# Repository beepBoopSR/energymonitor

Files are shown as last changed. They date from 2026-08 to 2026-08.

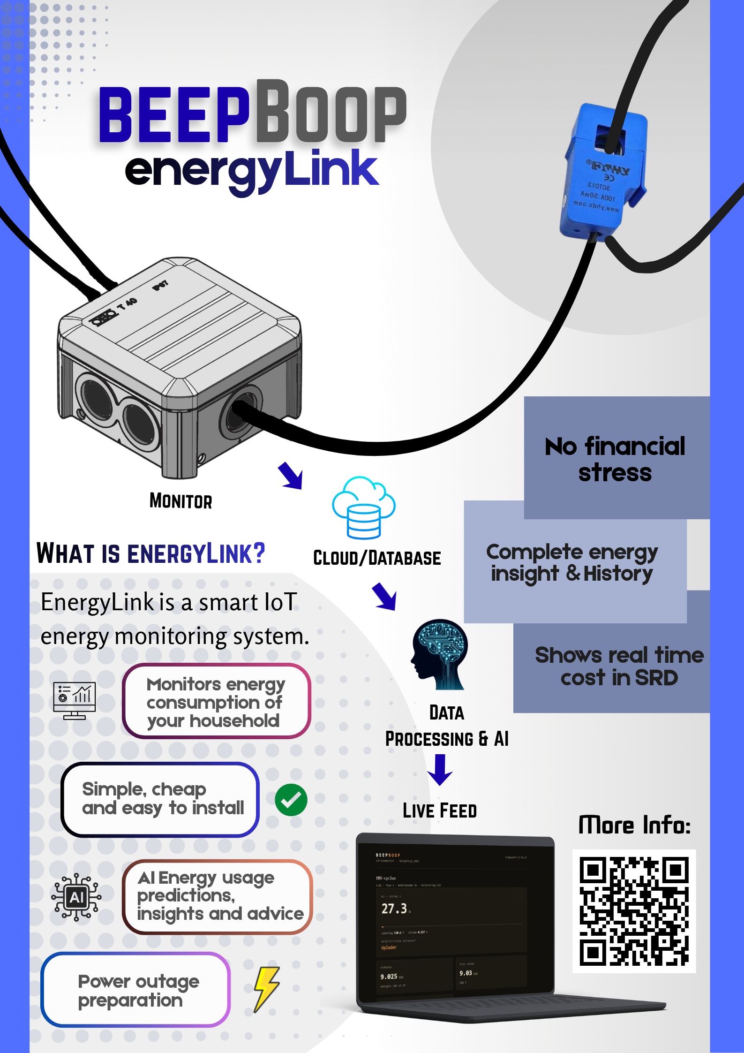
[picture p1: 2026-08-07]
Extras/beepBoop energylink poster.png

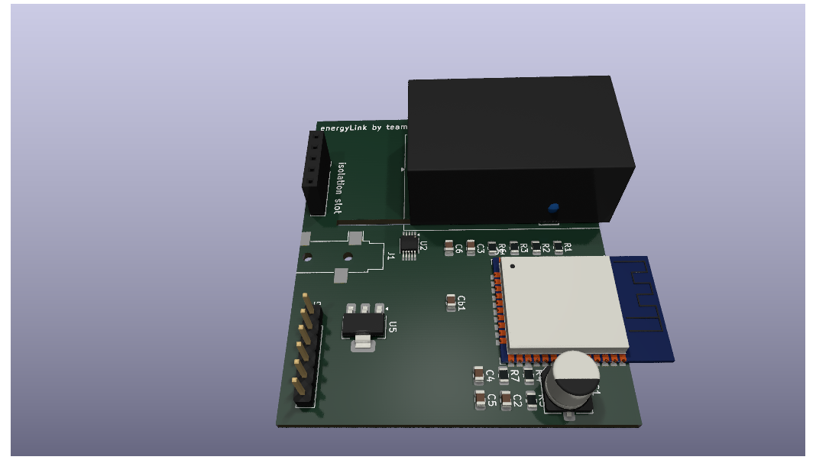
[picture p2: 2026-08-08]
energyLink PCB/Pictures 3D PCB/energyLink2.png

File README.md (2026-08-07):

# energyLink

**An AI home-energy monitor built for Surinamese households.**
team **beepBoop** · Hackomation 2026

energyLink clamps onto a home's main power line and continuously measures
consumption. For the first time, a household can watch its electricity bill build
in real time — in SRD, against the *actual* tiered EBS tariff — and get grounded,
practical advice in **Dutch and Sranan Tongo**, before the bill ever arrives.

---

## The problem it solves

- **The EBS household tariff is tiered.** The more you use, the more each next kWh
  costs — and the bill only arrives at the end of the cycle, as a surprise.
- **The grid is unstable.** Outages and brownouts are a daily reality.
- **Existing energy monitors don't fit Suriname.** They assume a stable grid, a flat
  tariff, and an English-speaking user, and none of them can tell you your EBS bill.

energyLink makes consumption, cost, and grid quality visible and predictable, in the
user's own language.

---

## What it does

- **Live power & live cost** — watts, volts, amps, and the cost *per hour* at the
  current draw, in SRD, updating in real time.
- **Accurate EBS billing** — tiered energy charge, per-phase basis fee, subsidy bands,
  and a bill prediction — all aligned to the household's EBS billing cycle, not the
  calendar month.
- **Tariff-band awareness** — shows where you sit across the tiers and how far to the
  next (more expensive) band.
- **Grid monitoring** — detects and logs outages and brownouts, with buffering so no
  data is lost when the power flickers.
- **AI advisory** — grounded, bilingual (Dutch + Sranan Tongo) advice based on the
  household's real measured data.
- **Appliance recognition** — a trained classifier identifies the *type* of the
  dominant load (resistive heater / motor / switching charger) from its current
  signature.
- **Per-circuit clamps** — support for naming and monitoring individual circuits.

---

## Architecture

```
  ESP32 + sensors            Node.js backend             Next.js frontend
  ───────────────            ───────────────             ────────────────
  ADS1115 (I²C)              POST /api/readings          polls /api/dashboard
  SCT-013 current   ──WiFi──▶  reconstruct time   ◀──HTTP──  every 5s, renders
  ZMPT101B voltage             store + analyse             live dashboard
                               SQL billing model
                                    │
                                    ▼
                               Supabase (Postgres)
```

- **Device → backend:** the ESP32 measures and POSTs readings; the backend
  reconstructs timestamps (handling offline buffering), stores them, and runs grid /
  anomaly / appliance checks on each reading.
- **Backend → frontend:** the frontend never talks to the device or database directly —
  it polls the backend's HTTP endpoints, which run the SQL billing model and return a
  single JSON payload.
- **Billing lives in the database** as data-driven SQL functions, so a tariff change is
  a data update, not a code change — and the same model serves the dashboard, the
  prediction, and the AI from one source of truth.

---

## Repository structure

```
energymonitor/
├── 3D-models hardware case/     3D model of an enclosure (designed but not used —
│                                 we bought an off-the-shelf case; kept for reference)
├── Back-end/                    Node.js + Express backend
│   ├── beepBoop-Back-End/       the runnable backend project (see below)
│   └── AI_training_appliance_models/   appliance-classifier training pipeline (see below)
├── C++ esp32 Firmwares/         ESP32 firmware — the full monitoring firmware, plus a
│                                 separate firmware used to capture waveforms for
│                                 appliance-fingerprint training
├── Extras/                      Business Model Canvas, poster, circuit diagram
├── SQL queries and functions/   Supabase schema, billing functions, seed data
├── api/                         API-related files
├── app/                         Next.js frontend (see below)
├── landingPage/                 Standalone marketing landing page
├── site/                        site assets
├── CLAUDE.md                    project notes
├── LICENSE
├── README.md                    this file
└── package.json
```

> The trees below list the **key files and their roles** — the important application
> code — rather than every file in the project. Config, generated, and dependency
> files are omitted for readability.

### Backend — `Back-end/beepBoop-Back-End/`

```
├── index.js                    Express app entry; registers routes, enables CORS
├── config/
│   └── supabase.js             configured Supabase client
├── routes/
│   ├── readings.js             POST /api/readings  ·  GET /api/dashboard
│   ├── tips.js                 GET /api/latest-tip  ·  POST /api/generate-tip
│   ├── settings.js             GET/POST /api/settings (phase, cycle, budget)
│   └── clamps.js               GET /api/clamps  ·  POST /api/clamps/rename
├── services/
│   ├── readings.js             reading ingestion + summary assembly
│   ├── reconstruction.js       timestamp reconstruction (offline buffering)
│   ├── gridMonitor.js          outage / brownout detection (with hysteresis)
│   ├── anomalyMonitor.js       power-spike + overuse detection
│   ├── applianceMonitor.js     appliance classifier — live inference
│   ├── energyContext.js        gathers the real context for the AI
│   ├── prompt.js               builds the grounded, bilingual AI prompt
│   ├── tips.js                 AI tip generation + retrieval
│   └── billPrediction.js       statistical bill projection (single source)
└── .env                        Supabase + Gemini keys (NOT committed)
```

### Appliance-classifier training — `Back-end/AI_training_appliance_models/`

```
├── 1_extract_features.py       waveform captures -> electrical features (CSV)
├── 2_train_model.py            train + cross-validate decision tree -> JSON
├── 3_inference_reference.js    reference of the JS inference (live in services/)
├── appliance_tree.json         the exported trained model
├── captures/                   example current-waveform captures
├── README.md                   pipeline documentation
└── NILM_future_work.md         why multi-appliance disaggregation was shelved
```

### Frontend — `app/app/`

```
├── app/
│   ├── page.tsx                redirects to /dashboard
│   ├── layout.tsx              sidebar shell (SidebarProvider)
│   ├── globals.css             energyLink light theme
│   ├── dashboard/page.tsx      main dashboard (live power, cost, tiers, AI, graphs)
│   ├── clamp/[id]/page.tsx     per-clamp detail (mini-dashboard + rename)
│   ├── uitval/page.tsx         outages (history)
│   ├── instellingen/page.tsx   settings (phase, EBS cycle, budget)
│   └── over/page.tsx           about / project story
├── components/
│   ├── app-sidebar.tsx         collapsible energyLink sidebar
│   ├── nav-main.tsx            nav items + active highlight
│   ├── nav-user.tsx            device identity footer
│   ├── clamps-section.tsx      dashboard Circuits section
│   └── ui/                     shadcn/ui components
├── lib/
│   └── api.ts                  API client, typed responses, mock data, USE_MOCK flag
├── next.config.ts
├── package.json
└── tsconfig.json
```

---

## Running it

Both the backend and the frontend must be running. The device (or synthetic data)
feeds the backend; the frontend polls the backend.

### Backend (port 3000)

```bash
cd Back-end
cd beepBoop-Back-End
node index.js
```

The backend serves on **port 3000** and exposes the API the frontend reads.

### Frontend (port 3001)

```bash
cd app
cd app
npm install          # first time only
npm run dev -- -p 3001
```

The frontend runs on **port 3001** (kept separate from the backend's 3000) and is
available at `http://localhost:3001`. Opening it redirects to the dashboard.

> The frontend fetches from the backend at `http://localhost:3000`. CORS is enabled on
> the backend so the cross-port requests are allowed. If the dashboard shows
> "kan geen verbinding maken," the backend isn't running or isn't reachable.

---

## Configuration

- **Backend:** environment variables for the Supabase connection and the AI (Gemini)
  API key live in the backend's environment (see the backend's own config). **Do not
  commit real keys.**
- **Frontend:** the API base URL and device id are set in the frontend's `lib/api.ts`.
  A `USE_MOCK` flag there switches between mock data and the live backend.
- **Database:** the SQL to create the schema, functions, and seed data is in
  `SQL queries and functions/` — run the table definitions first, then the functions,
  then the seed data.

---

## Firmware

The `C++ esp32 Firmwares/` folder contains two firmwares:

1. **Monitoring firmware** — the production firmware: samples voltage and current via
   the ADS1115, computes RMS/power/energy and waveform features, and POSTs readings to
   the backend over WiFi, with offline buffering and timestamp reconstruction.
2. **Fingerprint-capture firmware** — a separate build used during development to
   capture raw current waveforms of known appliances, for training the appliance
   classifier.

---

## Hardware

A sensing front-end around an ESP32:

- **ESP32 DevKit** — microcontroller with WiFi
- **ADS1115** — 16-bit I²C ADC (address 0x48; SDA→D21, SCL→D22)
- **SCT-013-000** — non-invasive current clamp, on the ADS1115 *differential* input
  A0–A1 with a 220 Ω burden resistor
- **ZMPT101B** — isolated AC voltage sensor, single-ended on A2

The circuit diagram is in `Extras/`. An enclosure 3D model is in
`3D-models hardware case/` (we used an off-the-shelf case in the end, but kept the
model).

---

## The AI, honestly scoped

energyLink uses AI in three distinct ways, and is deliberately precise about which is
which:

1. **Appliance recognition — trained machine learning.** A decision-tree classifier,
   trained on captured current waveforms, identifies the *type* of load from its
   electrical signature. (Training pipeline documented separately.)
2. **Advisory — a language model, grounded.** An LLM interprets the household's real
   computed data into personalized, bilingual advice, constrained so it never invents
   appliances or amounts.
3. **Anomaly detection — algorithmic.** Threshold-based spike and unusual-usage
   detection (not a trained model, and not described as one).

The **bill prediction is a transparent statistical projection, not AI** — we don't
dress it up as one. Multi-appliance disaggregation (NILM) was prototyped and shelved
for hardware reasons, documented as future work.

---

## Team

Built by team **beepBoop**, students at the Anton de Kom University of Suriname (ADeKUS),
for **Hackomation 2026**.

---

## License

See `LICENSE`.

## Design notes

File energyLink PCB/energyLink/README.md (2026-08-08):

# energyLink — KiCad project (team beepBoop)

Home energy monitor for Suriname's grid (120–127 V, 60 Hz). Clamps the main
live conductor, measures consumption, buffers to ESP32 flash when WiFi is down,
and infers mains outages from its own power-loss timestamps.

## Files
| File | What it is |
|---|---|
| `energyLink.kicad_sch` | Schematic — all components with net-label connectivity |
| `energyLink.kicad_pcb` | PCB — 55×40 mm outline, isolation slot, zoned placement |
| `energyLink.net` | Netlist — importable into Pcbnew if needed |
| `energyLink.kicad_pro` | Project file — open this in KiCad first |

Open `energyLink.kicad_pro` in KiCad 7 or 8.

## Please read — these files were generated programmatically
They are structurally valid and parse cleanly, but they were built without the
KiCad GUI, so treat them as a strong starting point, not a finished board:

1. Symbols are simple labelled rectangles with correct pins and nets. On first
   open, run **Inspect → Electrical Rules Check (ERC)**. Connectivity is carried
   by net labels on each pin, which is valid but will raise a few "no power flag"
   ERC notes — add PWR_FLAG on +3V3 / +5V / GND to clear them.
2. Footprints are named to standard KiCad libraries (`Converter_ACDC`,
   `RF_Module`, etc.). If a name doesn't resolve on your install, reassign via
   **Tools → Footprint Assignment**. The `.kicad_pcb` uses simplified 2-pad
   placeholders so you can see the zoned layout; swap in the real footprints
   before routing.
3. The PCB shows **placement and the isolation strategy**, not routed copper.
   Route it in Pcbnew — keep every mains trace inside the left zone.

## Design summary
- **Isolated SELV logic.** The only mains-referenced parts are J3, F1, RV1, the
  HLK-PM01 primary, and the ZMPT101B primary. CT, ZMPT, and HLK all isolate, so
  the ESP32/ADS1115 ground never touches mains — which is what makes the
  external 3.5 mm CT jack safe to handle.
- **Current:** SCT-013-000 → 3.5 mm jack → 22 Ω burden across ADS1115 A0–A1,
  biased to ~1.65 V via the VMID divider (R2/R3/Cb).
- **Voltage:** ZMPT101B isolated output → ADS1115 A2 (VSENSE).
- **Power:** HLK-PM01 (mains→5 V) → AMS1117-3.3 → 3V3. C1 470 µF bulk at the
  ESP32 prevents WiFi brownout resets.
- **Safety:** fuse + MOV on the line input; ≥6–8 mm creepage and a milled slot
  between mains and SELV zones (CAT III near a panel). A real product needs
  proper safety testing/certification and, in most places, electrician install.

## Productization notes (not in these files)
- Consider replacing the ADS1115 with an **ADE7953** metering IC for true active
  power / power factor (the ADS1115 multiplexes, so V and I aren't sampled
  simultaneously). Keep it inside the isolated domain, fed from the ZMPT output.
- **ESP32-C3-MINI-1** is smaller/cheaper and plenty for this workload.

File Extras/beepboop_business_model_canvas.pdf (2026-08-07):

# beepBoop — Business Model Canvas

AI-powered home energy monitor for Suriname · Team beepBoop, Anthon de Kom Universiteit van Suriname · Hackomation 2026

Draft v1 — July 2026

KEY PARTNERS

- EBS (Energiebedrijven Suriname) — tariff data, potential rollout partner
- Licensed electricians — panel installation network
- Local hardware importers (ESP32, sensors, clamps)
- Telesur / Digicel — connectivity for IoT data
- ADeKUS — engineering talent, credibility, pilot households
- Google (Gemini API) — AI advisory layer, model-agnostic by design

KEY ACTIVITIES

- Hardware assembly & per-unit calibration
- Firmware & platform development (offline-first)
- AI advisory: tips in Dutch & Sranan Tongo
- Tiered EBS billing engine & bill prediction
- Installation coordination with electricians

KEY RESOURCES

- Proprietary firmware: outage-resilient logging, timestamp reconstruction
- Tariff-aware billing engine (EBS block pricing)
- Sensor pipeline: current clamps + voltage sensing
- Growing dataset of Surinamese household usage
- Bilingual AI prompt & advisory system

VALUE PROPOSITIONS

- See your electricity bill BEFORE it arrives — tier-aware prediction
- Advice in your own language: Dutch & Sranan Tongo
- Built for Suriname's unstable grid: outage & brownout logging, offline-first
- Know which tariff tier you are in and how to stay under the next one
- Budget mode: set a monthly limit, get warned before you exceed it
- Evidence of grid quality (outage history) households can act on
- No smart meter required — clips onto existing breaker panel
- Future: per-appliance insight via AI fingerprinting

CUSTOMER RELATIONSHIPS

- Self-service dashboard (web app)
- AI advisor as ongoing personal touchpoint
- Installation moment = trust-building visit
- Community word-of-mouth (bill savings are visible)

CHANNELS

- Direct sales via landing page & social media
- Electrician referral network
- Hardware shops as resellers
- Future: EBS partnership channel

CUSTOMER SEGMENTS

- PRIMARY: Surinamese households on EBS household tariff, bill-sensitive, hit by tier jumps
- Households with frequent outages wanting grid evidence
- Budget-conscious families (subsidy-band households)
- SECONDARY: small businesses (niet-huishoudelijk flat 4.820/kWh — simpler billing, price-sensitive)
- FUTURE: groot verbruikers — time-of-use, kVA demand & power-factor optimisation (measurable ROI, no consumption cut needed)

COST STRUCTURE

- Per-unit hardware BOM: ESP32, ADS1115, SCT-013 clamp(s), ZMPT101B, PSU, enclosure
- Installation labour (electrician fee per unit) · Cloud & database hosting (Supabase)
- AI API usage (batched, ~fractions of a cent per advisory) · Support & calibration

REVENUE STREAMS

- Device sale (one-time, hardware + installation)
- Monthly subscription: AI advisory, bill prediction, outage history
- FUTURE: commercial tier for businesses (demand & power-factor analytics, premium pricing)
- FUTURE: anonymised consumption insights for utility planning (with consent)

# Notes, Assumptions & Open Questions

## Why this problem, why here

- EBS household billing is tiered (1.971 / 2.850 / 3.330 / 4.680 SRD per kWh, Dec 2024 sheet). Crossing a block raises the marginal price of every further kWh by up to 45%. Households cannot see this coming; beepBoop makes the tier position visible and predicts the bill.
- Grid instability is normal life in Suriname: the prototype has already logged real brownouts (down to 103 V) and outages during bench testing. Outage history is evidence households currently have no way to capture.
- Advisory in Sranan Tongo is a differentiator no imported product (Sense, Emporia) offers.

## What is proven vs. assumed

- PROVEN in prototype: calibrated current & voltage sensing, tiered billing engine, offline-first logging with timestamp reconstruction, outage/brownout detection, bilingual AI advisory grounded in measured data.
- ASSUMED, to validate: willingness to pay (device price & subscription level unset), installation cost per unit, subsidy band mechanics (placeholder 100 SRD in current build), whether Dec 2024 tariffs still hold.

## Unit economics (to be filled with real quotes)

- BOM target: components are commodity parts; production would replace the ADS1115 with a metering IC (e.g. ATM90E32) for multi-circuit and power-factor accuracy. Pricing decision pending importer quotes.
- AI cost per user is negligible at batched-advisory volumes (fractions of SRD 0.01 per tip on free/flash-tier models); the system is model-agnostic (Gemini today, swappable).

## Scaling path

- Households first (this canvas). Small business second: flat 4.820/kWh makes billing simpler than households.
- Groot verbruikers third: time-of-use tariffs, kVA demand charges and cosphi penalties mean businesses can cut bills without cutting consumption — load shifting, peak flattening, power-factor correction. Requires simultaneous-sampling metering hardware; a deliberate v2.

beepBoop · Hackomation 2026 · Tariff figures from EBS sheet dated December 2024 — verification pending. Subsidy amount is a placeholder.

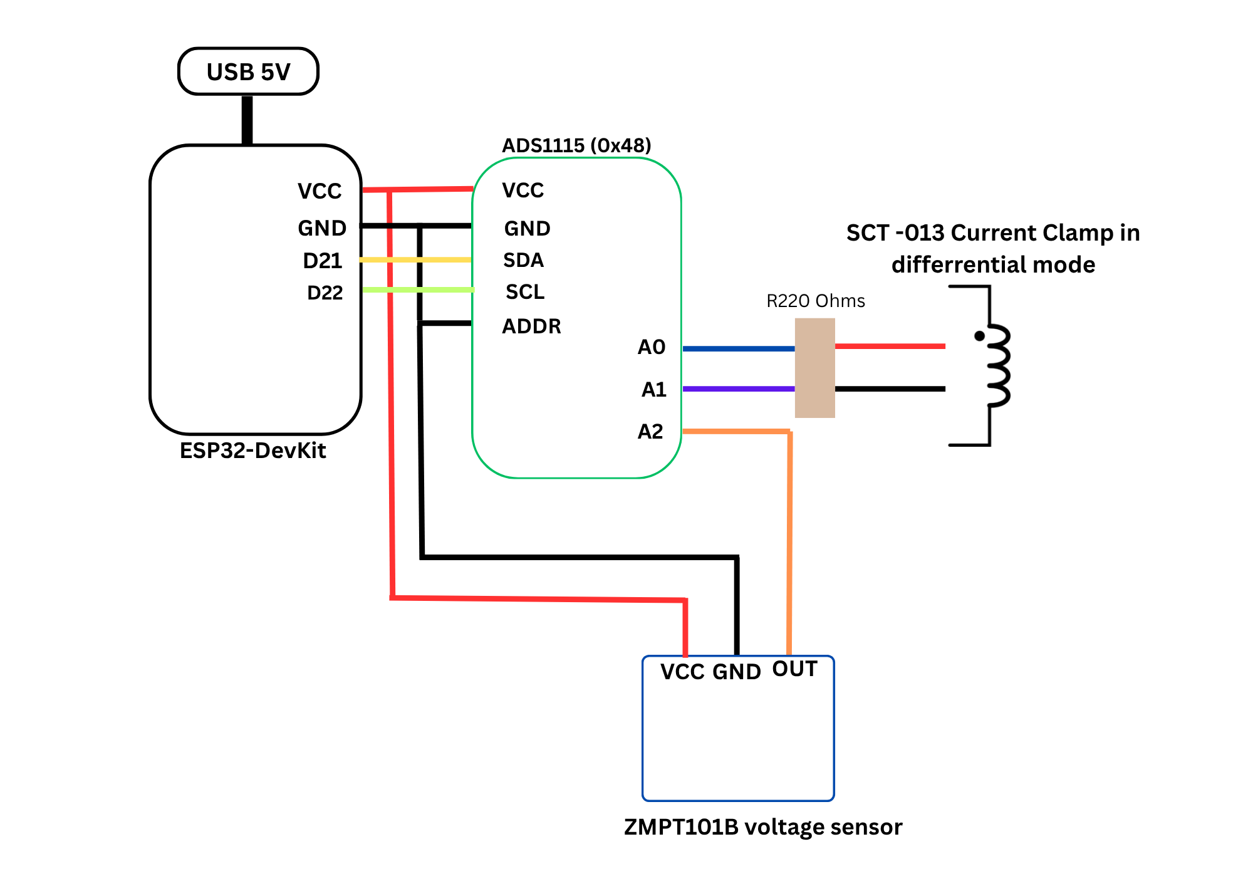
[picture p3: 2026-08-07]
Extras/hardwareCircuitDiaphgram.png

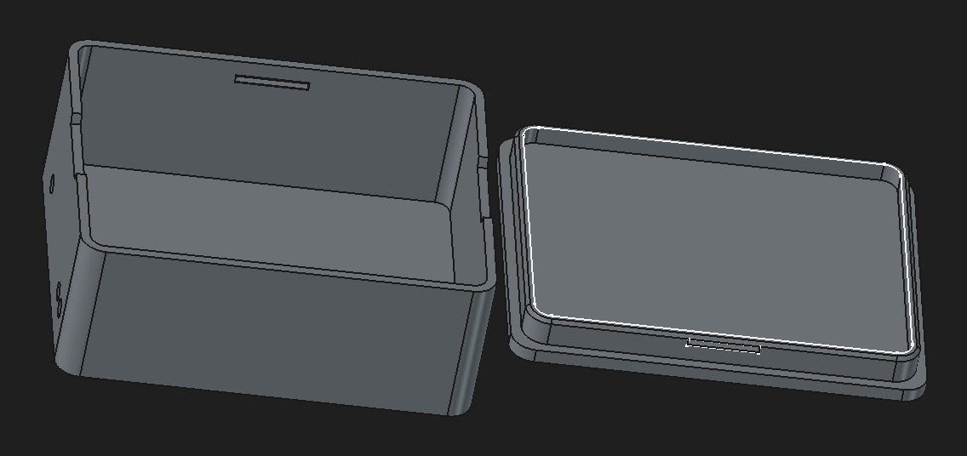
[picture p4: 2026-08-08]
3D-models hardware case/3d model picture.jpeg

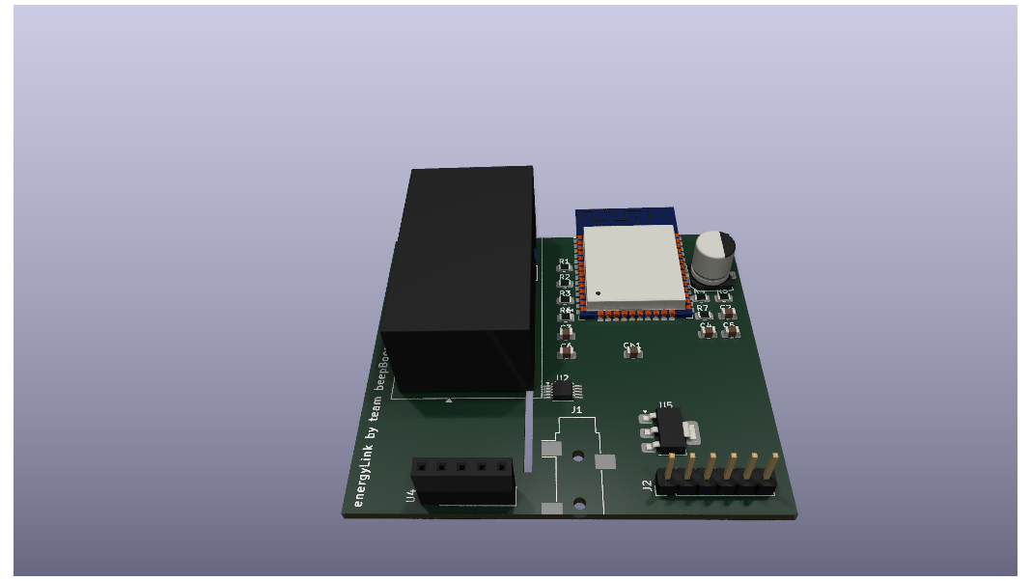
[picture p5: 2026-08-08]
energyLink PCB/Pictures 3D PCB/energyLink.png

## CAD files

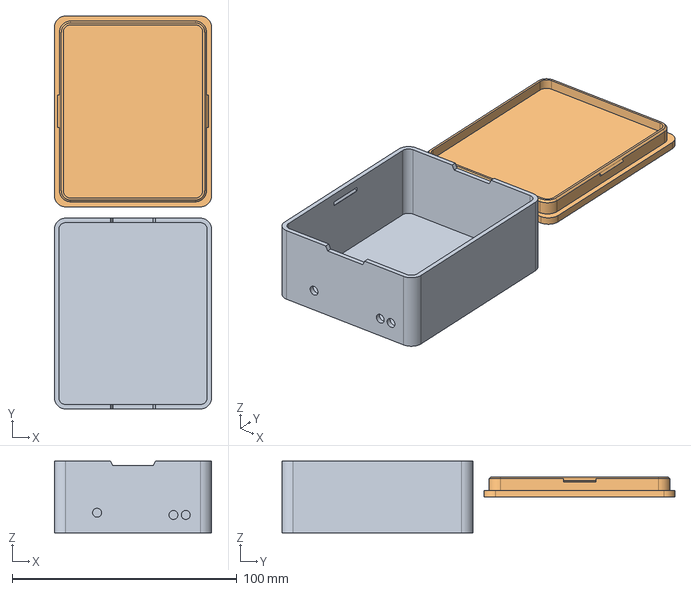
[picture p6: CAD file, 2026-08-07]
3D-models hardware case/energyLinkCase.FCStd
70.0 x 175.0 x 32.0 mm
lid

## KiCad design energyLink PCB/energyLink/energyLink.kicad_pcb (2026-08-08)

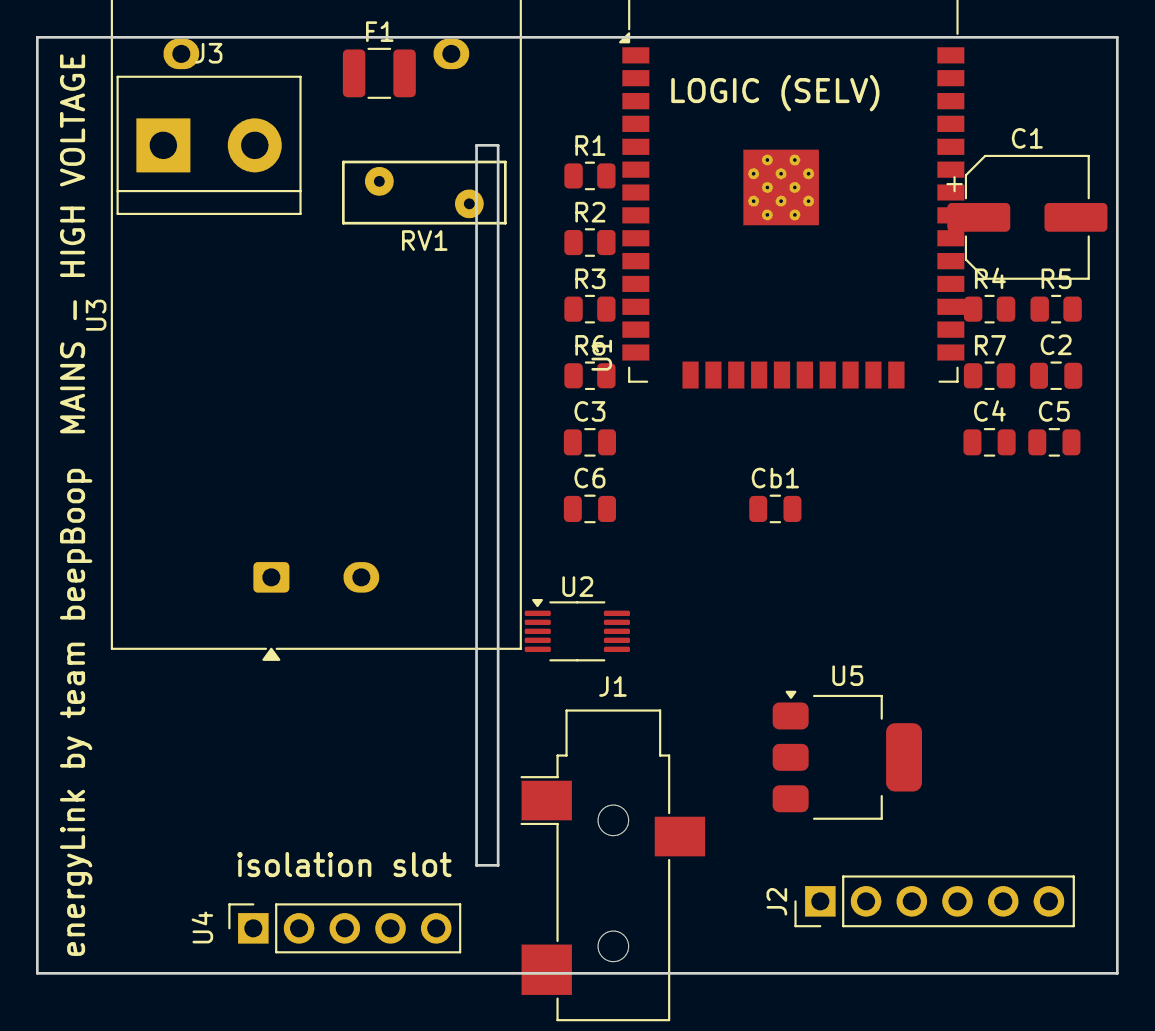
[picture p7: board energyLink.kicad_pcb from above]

Board: 2 copper layers, 60.0 x 52.0 mm, 24 parts (0 on the bottom side), 15 nets, no tracks yet.

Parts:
C1: 470uF_bulk; CP_Elec_6.3x7.7
C2, C3, C6: 100nF; C_0805_2012Metric
C4, C5: 10uF; C_0805_2012Metric
Cb1: 10uF_bias; C_0805_2012Metric
F1: Fuse_500mA_slow; Fuse_1210_3225Metric
J1: 3.5mm_CT_jack; Jack_3.5mm_CUI_SJ-3523-SMT_Horizontal
J2: Prog_1x6; PinHeader_1x06_P2.54mm_Vertical
J3: Mains_1x2; TerminalBlock_bornier-2_P5.08mm
R1: 22R_burden; R_0805_2012Metric
R2, R3: 100k; R_0805_2012Metric
R4: 4k7_SDA; R_0805_2012Metric
R5: 4k7_SCL; R_0805_2012Metric
R6: 10k_EN; R_0805_2012Metric
R7: 10k_IO0; R_0805_2012Metric
RV1: MOV_150VAC; RV_Disc_D9mm_W3.4mm_P5mm
U1: ESP32-WROOM-32
U2: ADS1115; VSSOP-10_3x3mm_P0.5mm
U3: HLK-PM01; Converter_ACDC_Hi-Link_HLK-PMxx
U4: ZMPT101B; PinSocket_1x05_P2.54mm_Vertical
U5: AMS1117-3.3; SOT-223-3_TabPin2

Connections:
/+3V3: C1.1, C2.1, C3.1, C5.1, J2.2 (3V3), R2.1, R4.2, R5.2, R6.2, R7.2, U1.1 (3V3), U2.1 (VDD), U4.3 (VCC), U5.3 (VOUT)
/+5V: C4.1, C6.1, U3.3 (+Vo), U5.1 (VIN)
/CT_A0: R1.1, U2.6 (A0)
/EN: J2.3 (EN), R6.1, U1.3 (EN)
/GND: C1.2, C2.2, C3.2, C4.2, C5.2, C6.2, Cb1.2, J2.1 (GND), R3.2, U1.2 (GND), U2.2 (GND), U2.5 (ADDR), U3.4 (-Vo), U4.5 (GND), U5.2 (GND)
/IO0: J2.4 (IO0), R7.1, U1.4 (IO0)
/L_FUSED: F1.2, RV1.1, U3.1 (L), U4.1
/L_IN: F1.1, J3.1 (L)
/N_MAINS: J3.2 (N), RV1.2, U3.2 (N), U4.2
/RX: J2.6 (RX), U1.8 (RXD0)
/SCL: R5.1, U1.6 (IO22_SCL), U2.3 (SCL)
/SDA: R4.1, U1.5 (IO21_SDA), U2.4 (SDA)
/TX: J2.5 (TX), U1.7 (TXD0)
/VMID: Cb1.1, R1.2, R2.2, R3.1, U2.7 (A1)
/VSENSE: U2.8 (A2), U4.4 (OUT)

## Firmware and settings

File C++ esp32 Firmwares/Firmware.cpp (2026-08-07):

#include <Wire.h>
#include <Adafruit_ADS1X15.h>
#include <WiFi.h>
#include <HTTPClient.h>
#include <time.h>
#include <LittleFS.h>

Adafruit_ADS1115 ads;

// WIFI + BACKEND
const char* WIFI_SSID     = "Ishaan's S23 FE";
const char* WIFI_PASSWORD = "ishaanoedit";
const char* SERVER_URL    = "http://10.182.168.64:3000/api/readings";
const char* DEVICE_ID     = "beepboop_001";

// SENSOR CALIBRATION
const float ADS_GAIN_VOLTS      = 0.0001875;
const float BURDEN_RESISTOR     = 22.0;
const int   CT_TURNS            = 2000;
const float CURRENT_FACTOR      = (float)CT_TURNS / BURDEN_RESISTOR;
const float CURRENT_CALIBRATION = 0.1255;   // 60W iron, verified with 30W
const float VOLTAGE_CALIBRATION = 1031.6;;     // multimeter @ 122.4V

// No tariff constant here — pricing is tiered and depends on the
// household's monthly cumulative total, which the device cannot know.
// The device reports energy; the database prices it.

// TIME (hardened)
const long  GMT_OFFSET_SEC      = -3 * 3600;
const int   DAYLIGHT_OFFSET_SEC = 0;
bool          timeIsSynced = false;
unsigned long lastSync     = 0;
const unsigned long SYNC_INTERVAL = 6UL * 3600UL * 1000UL;

// ADAPTIVE INTERVAL
const unsigned long INTERVAL_ONLINE    = 3000;
const unsigned long INTERVAL_OFFLINE_1 = 10000;
const unsigned long INTERVAL_OFFLINE_2 = 60000;
const unsigned long INTERVAL_OFFLINE_3 = 300000;
unsigned long offlineSince    = 0;
unsigned long lastSend        = 0;
unsigned long currentInterval = INTERVAL_ONLINE;

// STORAGE
const char*  BUFFER_FILE = "/buffer.txt";
const size_t MAX_BUFFER_BYTES = 1200000;

// STATE
long sequenceNumber = 0;

// SAMPLING
const unsigned long CURRENT_WINDOW_MS = 200;
const int CURRENT_AVG_WINDOWS = 5;
const int VOLTAGE_SAMPLES     = 256;

//For appliance fingerprinting
struct Features { float rms, peak, crest, form, shape; };

// Fast readings
struct Reading {
  float voltage, current, watts, kwh;
  float crest, form, shape, peak;
};

//For testing
unsigned long t;



void setup() {
  Serial.begin(115200);
  delay(1000);
  Serial.println("beepBoop — firmware v2 (energy reporting, tiered billing)");

  if (!LittleFS.begin(true)) { Serial.println("LittleFS failed."); while (1); }
  Wire.begin(21, 22);
  if (!ads.begin()) { Serial.println("ADS1115 not found."); while (1); }
  ads.setDataRate(RATE_ADS1115_860SPS);
  ads.setGain(GAIN_TWOTHIRDS);

  connectWiFi();
  Serial.print("Initial time sync");
  syncTime();
  Serial.println("Setup complete.\n");
}


// WIFI
void connectWiFi() {
  if (WiFi.status() == WL_CONNECTED) return;
  WiFi.begin(WIFI_SSID, WIFI_PASSWORD);
  int tries = 0;
  while (WiFi.status() != WL_CONNECTED && tries < 20) {
    delay(500); Serial.print("."); tries++;
  }
}


// HARDENED TIME
void syncTime() {
  configTime(GMT_OFFSET_SEC, DAYLIGHT_OFFSET_SEC,
             "pool.ntp.org", "time.google.com", "time.nist.gov");
  struct tm t; int tries = 0;
  while (!getLocalTime(&t) && tries < 10) { delay(500); Serial.print("."); tries++; }
  if (tries < 10) { timeIsSynced = true; lastSync = millis(); Serial.println(" synced"); }
  else Serial.println(" failed, will retry");
}

void maintainTime() {
  if (WiFi.status() == WL_CONNECTED &&
      (!timeIsSynced || millis() - lastSync > SYNC_INTERVAL)) syncTime();
}

String getTimestamp() {
  struct tm t;
  if (!timeIsSynced || !getLocalTime(&t)) return "UNSYNCED";
  char buf[25];
  sprintf(buf, "%04d-%02d-%02dT%02d:%02d:%02d",
          t.tm_year+1900, t.tm_mon+1, t.tm_mday, t.tm_hour, t.tm_min, t.tm_sec);
  return String(buf);
}


// ADAPTIVE INTERVAL 
unsigned long getInterval() {
  if (WiFi.status() == WL_CONNECTED) { offlineSince = 0; return INTERVAL_ONLINE; }
  if (offlineSince == 0) offlineSince = millis();
  unsigned long dur = millis() - offlineSince;
  if (dur < 10UL*60*1000)      return INTERVAL_OFFLINE_1;
  else if (dur < 60UL*60*1000) return INTERVAL_OFFLINE_2;
  else                         return INTERVAL_OFFLINE_3;
}

//VOLTAGE (A2 single-ended)

float readVoltage() {
  long sumRaw = 0; float sumSq = 0;
  for (int i = 0; i < VOLTAGE_SAMPLES; i++) sumRaw += ads.readADC_SingleEnded(2);
  float mid = (float)sumRaw / VOLTAGE_SAMPLES;
  for (int i = 0; i < VOLTAGE_SAMPLES; i++) {
    float s = ads.readADC_SingleEnded(2) - mid;
    float v = s * ADS_GAIN_VOLTS; sumSq += v*v;
  }
  float voltage = sqrt(sumSq / VOLTAGE_SAMPLES) * VOLTAGE_CALIBRATION;
  if (voltage < 20) voltage = 0.0;
  return voltage;
}

// UNIFIED READING — one current window feeds RMS + shape features

Reading takeReading(float elapsedSec) {
  const int N = 256;
  static int16_t buf[256];

  long sum = 0;
  for (int i = 0; i < N; i++) { buf[i] = ads.readADC_Differential_0_1(); sum += buf[i]; }
  float mid = (float)sum / N;

  float sumSq = 0, sumAbs = 0, peak = 0;
  for (int i = 0; i < N; i++) {
    float c = buf[i] - mid;
    sumSq += c*c; sumAbs += fabs(c);
    if (fabs(c) > peak) peak = fabs(c);
  }
  float rms_raw  = sqrt(sumSq / N);
  float mean_abs = sumAbs / N;

  Reading r;
  r.current = rms_raw * ADS_GAIN_VOLTS * CURRENT_FACTOR * CURRENT_CALIBRATION;
  if (r.current < 0.05) r.current = 0.0;
  r.peak    = peak    * ADS_GAIN_VOLTS * CURRENT_FACTOR * CURRENT_CALIBRATION;
  r.crest   = (rms_raw > 0) ? peak / rms_raw : 0;
  r.form    = (mean_abs > 0) ? rms_raw / mean_abs : 0;
  r.shape   = (rms_raw > 0) ? mean_abs / rms_raw : 0;

  r.voltage = readVoltage();
  r.watts   = r.voltage * r.current;
  r.kwh     = (r.watts / 1000.0) * (elapsedSec / 3600.0);
  return r;
}


String buildJson(int clampId, float voltage, float current,
                 float watts, float kwh, float elapsedSec,
                 float crest, float form, float shape, float peak) {
  sequenceNumber++;
  
  String json = "{";
  json += "\"device_id\":\"" + String(DEVICE_ID) + "\",";
  json += "\"clamp_id\":" + String(clampId) + ",";
  json += "\"timestamp\":\"" + getTimestamp() + "\",";
  json += "\"voltage\":" + String(voltage, 1) + ",";
  json += "\"current\":" + String(current, 3) + ",";
  json += "\"watts\":" + String(watts, 1) + ",";
  json += "\"interval_sec\":" + String(elapsedSec, 2) + ",";
  json += "\"kwh\":" + String(kwh, 8) + ",";
  json += "\"seq\":" + String(sequenceNumber) + ",";
  json += "\"ms_since_boot\":" + String(millis()) + ",";
  json += "\"time_status\":\"" + String(timeIsSynced ? "synced" : "unsynced") + "\",";  // <- comma added
  json += "\"crest\":" + String(crest, 3) + ",";
  json += "\"form\":"  + String(form, 3)  + ",";
  json += "\"shape\":" + String(shape, 3) + ",";
  json += "\"peak\":"  + String(peak, 3);   // <- no trailing comma, this is last
  json += "}";
  return json;
}


// POST 
bool postJson(String json) {
  if (WiFi.status() != WL_CONNECTED) return false;
  HTTPClient http;
  http.begin(SERVER_URL);
  http.addHeader("Content-Type", "application/json");
  int code = http.POST(json);
  http.end();
  return (code == 200 || code == 201);
}


// BUFFER 
void trimOldestReadings() {
  File f = LittleFS.open(BUFFER_FILE, "r");
  int total = 0;
  while (f.available()) { f.readStringUntil('\n'); total++; }
  f.close();
  int skip = total / 2;

  f = LittleFS.open(BUFFER_FILE, "r");
  File temp = LittleFS.open("/temp.txt", "w");
  int line = 0;
  while (f.available()) {
    String l = f.readStringUntil('\n');
    if (line >= skip) temp.println(l);
    line++;
  }
  f.close(); temp.close();
  LittleFS.remove(BUFFER_FILE);
  LittleFS.rename("/temp.txt", BUFFER_FILE);
  Serial.println("Buffer trimmed (kept newest half).");
}

void saveToBuffer(String json) {
  size_t size = 0;
  if (LittleFS.exists(BUFFER_FILE)) {
    File f = LittleFS.open(BUFFER_FILE, "r"); size = f.size(); f.close();
  }
  if (size > MAX_BUFFER_BYTES) trimOldestReadings();
  File f = LittleFS.open(BUFFER_FILE, "a");
  f.println(json); f.close();
  Serial.println("Stored offline.");
}

void flushBuffer() {
  if (!LittleFS.exists(BUFFER_FILE) || WiFi.status() != WL_CONNECTED) return;
  File f = LittleFS.open(BUFFER_FILE, "r");
  String remaining = ""; bool stopped = false;
  while (f.available()) {
    String line = f.readStringUntil('\n'); line.trim();
    if (line.length() == 0) continue;
    if (stopped) { remaining += line + "\n"; continue; }
    if (postJson(line)) { /* uploaded, drop it */ }
    else { remaining += line + "\n"; stopped = true; }
  }
  f.close();
  if (remaining.length() == 0) {
    LittleFS.remove(BUFFER_FILE);
    Serial.println("Buffer cleared.");
  } else {
    File w = LittleFS.open(BUFFER_FILE, "w"); w.print(remaining); w.close();
    Serial.println("Kept unsent readings.");
  }
}


//  SERIAL COMMANDS 
void dumpBuffer() {
  if (!LittleFS.exists(BUFFER_FILE)) { Serial.println("Buffer empty."); return; }
  File f = LittleFS.open(BUFFER_FILE, "r");
  int n = 0;
  Serial.println("───── BUFFER ─────");
  while (f.available()) {
    String l = f.readStringUntil('\n'); l.trim();
    if (l.length()) { Serial.println(l); n++; }
  }
  f.close();
  Serial.println("───── " + String(n) + " readings ─────");
}


// MAIN LOOP 
void loop() {
  if (Serial.available()) {
    char c = Serial.read();
    if (c == 'd') dumpBuffer();
    if (c == 'c') { LittleFS.remove(BUFFER_FILE); Serial.println("Buffer cleared."); }
  }

  currentInterval = getInterval();
  if (millis() - lastSend < currentInterval) return;

  // Measure the interval this reading actually represents
  unsigned long nowMs   = millis();
  unsigned long elapsed = (lastSend == 0) ? currentInterval : (nowMs - lastSend);
  lastSend = nowMs;
  float elapsedSec = elapsed / 1000.0;

  if (WiFi.status() != WL_CONNECTED) connectWiFi();
  maintainTime();
  flushBuffer();

  Reading r = takeReading(elapsedSec);
  String json = buildJson(1, r.voltage, r.current, r.watts, r.kwh,
                        elapsedSec, r.crest, r.form, r.shape, r.peak);

  Serial.print("seq "); Serial.print(sequenceNumber);
  Serial.print(" | "); Serial.print(r.voltage, 1); Serial.print("V ");
  Serial.print(r.current, 3); Serial.print("A ");
  Serial.print(r.watts, 1);   Serial.print("W | ");
  Serial.print(r.kwh, 8);     Serial.print(" kWh over ");
  Serial.print(elapsedSec, 1); Serial.print("s | ");
  Serial.println(getTimestamp());

  if (postJson(json)) Serial.println("Sent live → OK");
  else saveToBuffer(json);
}

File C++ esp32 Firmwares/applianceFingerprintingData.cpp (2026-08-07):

//Deze firmware was gebruikt om de data te verzamelen voor appliance fingerprinting

#include <Wire.h>
#include <Adafruit_ADS1X15.h>

Adafruit_ADS1115 ads;

// !!!code runnde eerst met 220 ohms, maar calibration factor was van 22 ohms. dus alles was 10x kleiner. ik heb de burden_resistor constant verandert, maar sinds de code niet gerunned 

const float ADS_GAIN_VOLTS      = 0.0001875;
const float BURDEN_RESISTOR     = 22.0;   // your actual resistor
const int   CT_TURNS            = 2000;
const float CURRENT_FACTOR      = (float)CT_TURNS / BURDEN_RESISTOR;
const float CURRENT_CALIBRATION = 0.1255;  // note: paired with the 220R, leave as-is

// Capture window: long enough for many cycles, fast as the ADS allows
const int   SAMPLES = 400;                 // ~0.5s of samples at 860 SPS

void setup() {
  Serial.begin(115200);
  delay(1000);
  Wire.begin(21, 22);
  if (!ads.begin()) { Serial.println("ADS1115 not found."); while (1); }
  ads.setDataRate(RATE_ADS1115_860SPS);
  ads.setGain(GAIN_TWOTHIRDS);
  Serial.println("beepBoop — appliance feature capture");
  Serial.println("Type a label + Enter (e.g. 'grill') to capture one sample.\n");
  Serial.println("label,rms_a,peak_a,crest,form,zero_cross,shape");
}

void captureFeatures(String label) {
  int16_t buf[SAMPLES];
  long sum = 0;

  // Grab the raw window
  for (int i = 0; i < SAMPLES; i++) { buf[i] = ads.readADC_Differential_0_1(); sum += buf[i]; }
  float mid = (float)sum / SAMPLES;

  // Derived features
  float sumSq = 0, sumAbs = 0, peak = 0;
  int   zeroCross = 0;
  float prev = buf[0] - mid;

  for (int i = 0; i < SAMPLES; i++) {
    float c = buf[i] - mid;
    sumSq  += c * c;
    sumAbs += fabs(c);
    if (fabs(c) > peak) peak = fabs(c);
    if ((c > 0 && prev <= 0) || (c < 0 && prev >= 0)) zeroCross++;
    prev = c;
  }

  float rms_raw  = sqrt(sumSq / SAMPLES);
  float mean_abs = sumAbs / SAMPLES;

  // Convert the electrical ones to amps using your calibration
  float rms_a  = rms_raw * ADS_GAIN_VOLTS * CURRENT_FACTOR * CURRENT_CALIBRATION;
  float peak_a = peak    * ADS_GAIN_VOLTS * CURRENT_FACTOR * CURRENT_CALIBRATION;

  // Shape features — unit-less, describe the waveform not its size
  float crest = (rms_raw > 0) ? peak / rms_raw : 0;        // peakiness
  float form  = (mean_abs > 0) ? rms_raw / mean_abs : 0;   // form factor
  float shape = (rms_raw > 0) ? mean_abs / rms_raw : 0;    // inverse form

  // CSV line
  Serial.print(label);        Serial.print(",");
  Serial.print(rms_a, 3);     Serial.print(",");
  Serial.print(peak_a, 3);    Serial.print(",");
  Serial.print(crest, 3);     Serial.print(",");
  Serial.print(form, 3);      Serial.print(",");
  Serial.print(zeroCross);    Serial.print(",");
  Serial.println(shape, 3);
}

void loop() {
  if (Serial.available()) {
    String label = Serial.readStringUntil('\n');
    label.trim();
    if (label.length() > 0) captureFeatures(label);
  }
}

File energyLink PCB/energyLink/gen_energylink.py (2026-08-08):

#!/usr/bin/env python3
"""Generate a KiCad 7 project (schematic + PCB + netlist) for the energyLink
home energy monitor by team beepBoop, from a single source-of-truth model.

Connectivity in the schematic is carried by net labels placed on short wire
stubs at each pin's connection point, so the same design drives the schematic,
the .net file, and the PCB placement.
"""
import uuid, datetime, os

def U(): return str(uuid.uuid4())

DATE = datetime.date.today().isoformat()
PROJ = "energyLink"
ROOT_UUID = U()

# ---------------------------------------------------------------------------
# SOURCE OF TRUTH: components and their pins.
# Each pin: (number, name, net, side)  side in {"L","R"}
# ---------------------------------------------------------------------------
COMPONENTS = [
    dict(ref="U1", value="ESP32-WROOM-32", fp="RF_Module:ESP32-WROOM-32",
         sym="ESP32_WROOM_32",
         pins=[("1","3V3","+3V3","L"),("2","GND","GND","L"),
               ("3","EN","EN","L"),("4","IO0","IO0","L"),
               ("5","IO21_SDA","SDA","R"),("6","IO22_SCL","SCL","R"),
               ("7","TXD0","TX","R"),("8","RXD0","RX","R")]),
    dict(ref="U2", value="ADS1115", fp="Package_TSSOP:TSSOP-10_3x3mm_P0.5mm",
         sym="ADS1115",
         pins=[("1","VDD","+3V3","L"),("2","GND","GND","L"),
               ("3","SCL","SCL","L"),("4","SDA","SDA","L"),("5","ADDR","GND","L"),
               ("6","A0","CT_A0","R"),("7","A1","VMID","R"),
               ("8","A2","VSENSE","R"),("9","A3","NC","R")]),
    dict(ref="U3", value="HLK-PM01", fp="Converter_ACDC:Converter_ACDC_HLK-PMxx",
         sym="HLK_PM01",
         pins=[("1","L","L_FUSED","L"),("2","N","N_MAINS","L"),
               ("3","+Vo","+5V","R"),("4","-Vo","GND","R")]),
    dict(ref="U4", value="ZMPT101B", fp="Transformer_THT:Transformer_ZMPT101B",
         sym="ZMPT101B",
         pins=[("1","P1","L_FUSED","L"),("2","P2","N_MAINS","L"),
               ("3","VCC","+3V3","R"),("4","OUT","VSENSE","R"),("5","GND","GND","R")]),
    dict(ref="U5", value="AMS1117-3.3", fp="Package_TO_SOT_SMD:SOT-223-3_TabPin2",
         sym="AMS1117_33",
         pins=[("1","VIN","+5V","L"),("2","GND","GND","L"),("3","VOUT","+3V3","R")]),
    dict(ref="J1", value="3.5mm_CT_jack", fp="Connector_Audio:Jack_3.5mm_CUI_SJ1-3533N",
         sym="JACK_CT",
         pins=[("1","TIP","CT_A0","L"),("2","SLEEVE","VMID","L")]),
    dict(ref="J2", value="Prog_1x6", fp="Connector_PinHeader_2.54mm:PinHeader_1x06_P2.54mm_Vertical",
         sym="HDR_PROG",
         pins=[("1","GND","GND","R"),("2","3V3","+3V3","R"),("3","EN","EN","R"),
               ("4","IO0","IO0","R"),("5","TX","TX","R"),("6","RX","RX","R")]),
    dict(ref="J3", value="Mains_1x2", fp="TerminalBlock:TerminalBlock_bornier-2_P5.08mm",
         sym="TERM_MAINS",
         pins=[("1","L","L_IN","L"),("2","N","N_MAINS","L")]),
    dict(ref="F1", value="Fuse_500mA_slow", fp="Fuse:Fuse_1210_3225Metric",
         sym="FUSE", pins=[("1","1","L_IN","L"),("2","2","L_FUSED","R")]),
    dict(ref="RV1", value="MOV_150VAC", fp="Varistor:RV_Disc_D9mm_W3.4mm_P5mm",
         sym="MOV", pins=[("1","1","L_FUSED","L"),("2","2","N_MAINS","R")]),
    dict(ref="R1", value="22R_burden", fp="Resistor_SMD:R_0805_2012Metric",
         sym="R", pins=[("1","1","CT_A0","L"),("2","2","VMID","R")]),
    dict(ref="R2", value="100k", fp="Resistor_SMD:R_0805_2012Metric",
         sym="R", pins=[("1","1","+3V3","L"),("2","2","VMID","R")]),
    dict(ref="R3", value="100k", fp="Resistor_SMD:R_0805_2012Metric",
         sym="R", pins=[("1","1","VMID","L"),("2","2","GND","R")]),
    dict(ref="R4", value="4k7_SDA", fp="Resistor_SMD:R_0805_2012Metric",
         sym="R", pins=[("1","1","SDA","L"),("2","2","+3V3","R")]),
    dict(ref="R5", value="4k7_SCL", fp="Resistor_SMD:R_0805_2012Metric",
         sym="R", pins=[("1","1","SCL","L"),("2","2","+3V3","R")]),
    dict(ref="R6", value="10k_EN", fp="Resistor_SMD:R_0805_2012Metric",
         sym="R", pins=[("1","1","EN","L"),("2","2","+3V3","R")]),
    dict(ref="R7", value="10k_IO0", fp="Resistor_SMD:R_0805_2012Metric",
         sym="R", pins=[("1","1","IO0","L"),("2","2","+3V3","R")]),
    dict(ref="C1", value="470uF_bulk", fp="Capacitor_SMD:CP_Elec_6.3x7.7",
         sym="C", pins=[("1","1","+3V3","L"),("2","2","GND","R")]),
    dict(ref="C2", value="100nF", fp="Capacitor_SMD:C_0805_2012Metric",
         sym="C", pins=[("1","1","+3V3","L"),("2","2","GND","R")]),
    dict(ref="C3", value="100nF", fp="Capacitor_SMD:C_0805_2012Metric",
         sym="C", pins=[("1","1","+3V3","L"),("2","2","GND","R")]),
    dict(ref="C4", value="10uF", fp="Capacitor_SMD:C_0805_2012Metric",
         sym="C", pins=[("1","1","+5V","L"),("2","2","GND","R")]),
    dict(ref="C5", value="10uF", fp="Capacitor_SMD:C_0805_2012Metric",
         sym="C", pins=[("1","1","+3V3","L"),("2","2","GND","R")]),
    dict(ref="C6", value="100nF", fp="Capacitor_SMD:C_0805_2012Metric",
         sym="C", pins=[("1","1","+5V","L"),("2","2","GND","R")]),
    dict(ref="Cb", value="10uF_bias", fp="Capacitor_SMD:C_0805_2012Metric",
         sym="C", pins=[("1","1","VMID","L"),("2","2","GND","R")]),
]

# unique symbol geometry
def sym_geom(sym):
    comp = next(c for c in COMPONENTS if c["sym"] == sym)
    left = [p for p in comp["pins"] if p[3] == "L"]
    right = [p for p in comp["pins"] if p[3] == "R"]
    rows = max(len(left), len(right), 1)
    H = rows * 2.54 + 5.08
    W = 25.4 if sym in ("ESP32_WROOM_32","ADS1115","ZMPT101B","HLK_PM01") else 15.24
    return left, right, W, H

def pin_local(sym, number):
    """Return (lx, ly, angle, side) of a pin's connection point in symbol-local coords."""
    left, right, W, H = sym_geom(sym)
    comp = next(c for c in COMPONENTS if c["sym"] == sym)
    pins = comp["pins"]
    L = 2.54
    def col(side_pins, side):
        n = len(side_pins)
        top = (n - 1) * 2.54 / 2.0
        out = {}
        for i, p in enumerate(side_pins):
            y = top - i * 2.54
            if side == "L":
                out[p[0]] = (-W/2 - L, y, 0)
            else:
                out[p[0]] = (W/2 + L, y, 180)
        return out
    m = {}
    m.update(col(left, "L")); m.update(col(right, "R"))
    lx, ly, a = m[number]
    return lx, ly, a
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

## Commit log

2026-07-01 Fix nested repo, track app/app as regular files
2026-08-03 Added beepBoop landing page
2026-08-07 changes to page preview and layouts. Also functionality of per clamp reading
2026-08-07 Added energyLink case 3D model
    [energyLinkCase.FCStd]
2026-08-07 ref mirros editing so the polling interval always reads the current value, and is not affected by the interval refresh. Now the name wont overwrite mid typing
2026-08-07 Feutires button was double, changed it to 1
2026-08-08 Added github button to landing page
2026-08-08 Added PCB files to github repo
    [energyLink.kicad_pcb, energyLink.kicad_sch]
2026-08-08 Added ability for the user to manually add clamps
2026-08-08 Added presentation Pitch
2026-08-08 Added 3d model of case
2026-08-12 Updated presentation pitch
